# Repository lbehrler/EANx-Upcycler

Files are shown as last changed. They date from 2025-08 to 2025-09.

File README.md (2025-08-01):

# EANx-Upcycler

This proeject is the enhanced feature version on Platform IO of this project https://github.com/lbehrler/EANx-Analyzer-Arduino

# EANx-Analyzer-Arduino / ESP32 

> **Note:** If you have an issue with this project, please review your hardware docuemntation first.  If you are still having an issue or have a software specific issue, please open an issue [here](https://github.com/lbehrler/EANx-Upcycler/issues).

EANx Analysis with output to an OLED color display.
The code can be customized to match a wide variety of hardware.  The current version in the main branch is setup to use an ESP32-Pico-D4, a Seeeduino Xiao, or an Arduino Nano with an SPI interface OLED screen 240 x 240.

In its simplest form the EANx Analyzer reads an analog input from an ADS1115, converts it to voltage, grabs a running average of ADC values and and prints the result to the display and debug to Serial Monitor.

The EANx Analyzer project is meant to be a DIY O2 Analyzer.  

## Disclaimers

**Using or monitoring oxygen levels above atmospheric composition (20.9%) can be hazardous. While oxygen is not combustible or explosive, its presence accelerates and promotes combustion. High levels of oxygen will make most materials combustible including metals. Do not use oxygen levels above 20.9% in the presence of any flame or ignition source.**

**Use at your own risk.  Inaccurate gas analysis can lead to serious personal injury or death.**  

If you are using the device and software for critical purposes, please seek proper training and know the limits of devices of this type. By using this analyzer to analyze breathing gas, you assume all risks for the use of analyzed gas and the risk from any inferences made from the output of the device, both above and below the water.

## Acknowledgements
Some of this code is adapted from other EANx project scripts: 
  - https://github.com/ppppaoppp/DIY-Nitrox-Analyzer-04_12_2019.git
  - https://github.com/ejlabs/arduino-nitrox-analyzer.git

## Basic Operations 
Unit is rechargeable with any 5-20v USB-C negotiating charger (i.e. phone charger).  The unit has a battery meter in the upper right of the screen for the 16340 battery status, and in the upper left for the sensor unit.   If the sensor unit is yellow or red, please replace the O2 sensor, if the battery monitor is yellow or red please fully charge the unit before use. 

### Firmware and Package Upates
The recommended method for firmware updates or to reflash your device is to use the browser based updater here:  ([Firmware Update Page](https://lbehrler.github.io/EANxUpcycler.github.io/)).

Alternately updates can be made using Expressif's ESP Flash Download Tool or an online Serial Connection tool (https://serial.huhn.me/) to update the firmware on your device.  Do so with caution the firmware portion starts at 0x10000 memory position. 

## Project Files

The project folder contains several files and one folder:

+ `LICENSE` - The license file for this project
+ `readme.md` - This file.
+ `EANx_Analyzer_XXXXXXX.ino` - the basic application.
+ `pin_config.h` - Header file for various ESP32 / Arduino pinout settings. 
+ `OTA.h` - Simple OTA upate header (optional utility).
+ `bat_stat.h` - Simple Battery status script for ESP32 based boards.

## Configuration
Depending on your hardware configuration and components used you will have to set your pin definitions in the header files. 

If you are using a basic ST3%XX or ST13XX series display you can use [U8g2](https://github.com/olikraus/u8g2) or the Adafruit librarires. For more advance display features and better efficiency the [Bodmer TFT eSPI library](https://github.com/Bodmer/TFT_eSPI) can be configured allowing for greater options. If you are using the EANx Analyzer OLED TFT eSPI.ino then the TFT eSPI library is required. 

## Revision History
+ 11/29/2022 - initial release
+ 12/30/2022 - prototype release
+ 01/03/2023 - custom PCB prototype release
+ 07/20/2023 - custom PCB option ESP32 release

## Schematics 

*Seeeduino Xiao version with SPI OLED:*


## Prototype

The current prototype unit is built using:
+ LilyGo-T-OI-PLUS [ESP32 C3 with 16340 Battery holder](https://github.com/Xinyuan-LilyGO/LilyGo-T-OI-PLUS)
+ Generic ADS1115 
+ SPI Organic light-emitting diode (OLED) ST7789
+ O2 Sensor
+ 16340 Battery
+ Custom PCB fit to project case
+ Project case

*Prototype 4 (2023)*

Custom PCB version

*Prototype 5 (2024)*

Updated 2024 Custom PCB version

Updated 2024 Custom PCB version compared to prior prototype

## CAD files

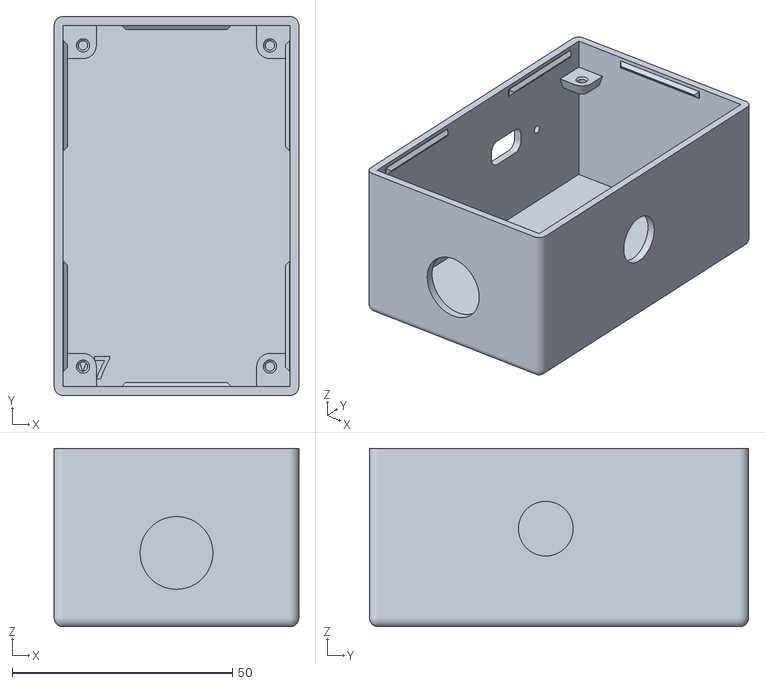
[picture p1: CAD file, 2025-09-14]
STL/Box - V7.stl
55.5 x 86.0 x 40.5

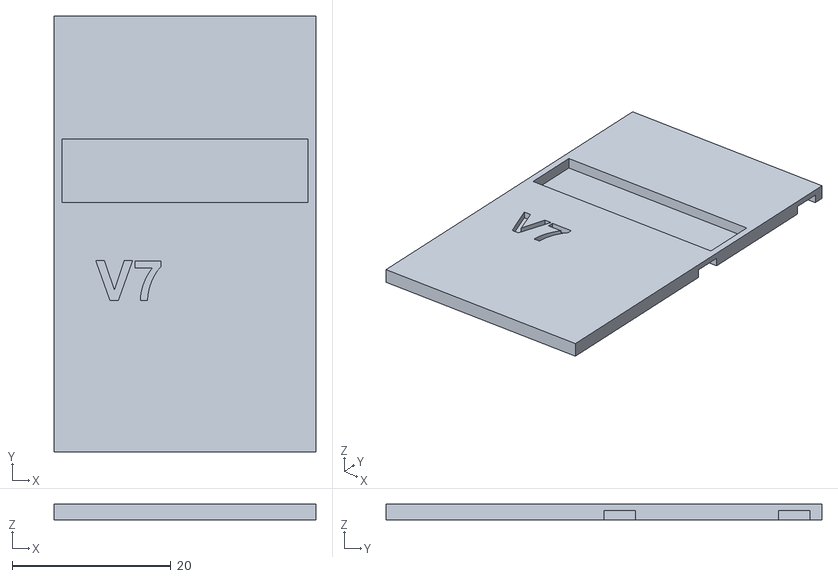
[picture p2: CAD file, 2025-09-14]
STL/XL Spacer V7.stl
33.0 x 55.0 x 2.00

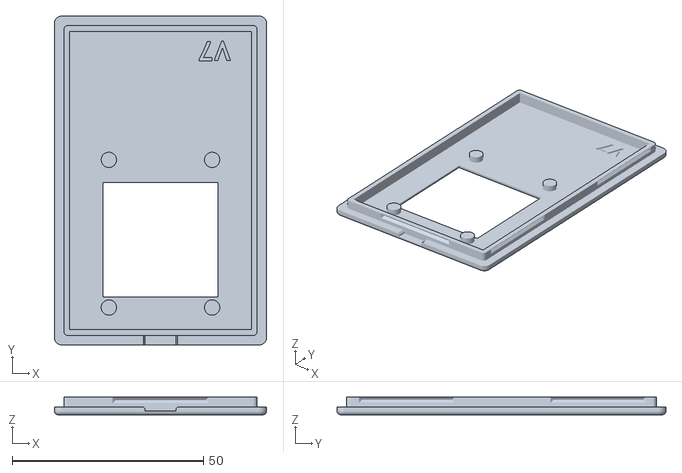
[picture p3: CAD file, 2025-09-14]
STL/Lid - V7.stl
55.5 x 86.0 x 4.60

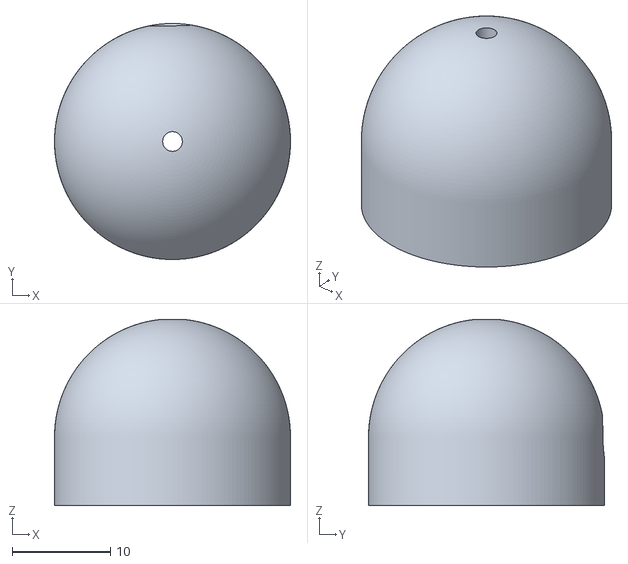
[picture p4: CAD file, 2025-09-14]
STL/Nozzle V7.stl
24.0 x 24.0 x 19.0

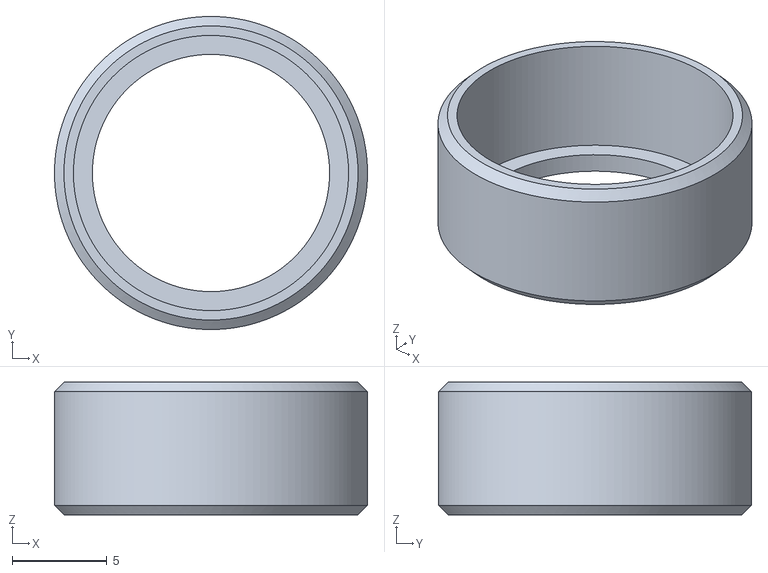
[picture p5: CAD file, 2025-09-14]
STL/Switch Shroud V7.stl
16.5 x 16.5 x 7.00

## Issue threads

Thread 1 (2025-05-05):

Missing information

Itzikiver, 2025-05-05:
Hi, thanks for this amazig project!
One thing i think is missing is the connection diagram between the batterry module and the whole circuit.
If you could added this it would be helpful, thanks again!

Itzikiver, 2025-05-05:
Thanks for replay.
I'm using the same modules you mentioned but I didn't get how did you power the whole circuit and how you passed the battery state to the xiao-c3 to display on the screen.

lbehrler, 2025-05-05:
Ah good question if you look at the Fritzing diagram the power from the battery comes into the Seeeduino Xiao in pin 1-3 depending on voltage.  The on off switch can be inserted between the positive contact and the battery.   Note for Seeed devices from their datasheet:

```
For general I/O pins: Working voltage of MCU is 3.3V. Voltage input connected to general I/O pins may cause chip damage if it' higher than 3.3V .

For power supply pins: The built-in DC-DC converter circuit able to change 5V voltage into 3.3V allows to power the device with a 5V supply via VIN-PIN and 5V-PIN.

XIAO SAMD21 currently only supports battery power supply and cannot connect to Type-C while a battery is connected, as it may pose a safety risk.

Please pay attention to use, do not lift the shield cover.
```

With that said you will need to leave the switch on to charge.   The voltage for the battery is pulled from the internal register in the ESP 32 that indicates voltage in.  From this the battery meter is populated using this function include/bat_stat.h

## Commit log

2025-05-15 Updated STLs
    Fixed Corrupted STL files
    [EANx Box V6 R1 - Complete Assembly.stl, EANx Box V6-Body 2025.stl.stl, EANx Lid V6-Lid 2025.stl.stl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]
2025-05-15 Remove old STL files
    Fix corrupted files
    [EAN Box V6.step, EAN Box V6.stl, EAN Cap V2.step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]
2025-08-01 Update README.md
    Added photos of Prototype 5
2025-09-14 Add files via upload
    Updated 3d print files
    [Box - V7.stl, Lid - V7.stl, Nozzle V7.stl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]
2025-09-14 Cleanup of old files
    [EANx Box V6 R1 - Complete Assembly.stl, EANx Box V6-Body 2025.stl.stl, EANx Lid V6-Lid 2025.stl.stl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]
